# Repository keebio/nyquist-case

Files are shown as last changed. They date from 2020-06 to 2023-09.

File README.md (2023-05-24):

Nyquist Keyboard Case
=====================

Here's case design files for the [Nyquist](https://keeb.io/collections/nyquist-parts). It's a sandwich-style case with cutouts at the back to accomodate the USB jack and the TRRS jack.

There are a few different designs included in this repository, one case with 9 screw holes around the exterior of the plate (`exterior-screws` directory), and one with 4 screw holes on the interior of the plate (i.e. all but one screw is hidden from view) (`interior-screws` directory). The latest design is the [Enclosed Case](enclosed-case/) in the `enclosed-case` directory.

Exterior case pieces
--------------------
The design file for the exterior screw case has 2 top, 2 bottom, and 8 middle layer pieces. This is good for 1 complete case for 2 halves.

There's 4 different types of pieces the case uses:

- Top/Switch layer - Each half uses 1 of these
    - There are 3 different versions
    - `switch-layer-1u.svg` - All 1u keys
    - `switch-layer-2u.svg` - 2u key at lower right (or lower left if plate is flipped for other half)
    - `switch-layer-universal.svg` - Supports both 1u and 2u configuration
- Bottom layer (`bottom-layer.svg`) - Each half uses 1 of these
- Middle layer (`middle-layer.svg`)
    - C-shaped piece - Each half uses 3 of these, use a 4th one if you need more space (like when using a Pro Micro with Mini USB jack)
    - Stick piece - Same number as the C-Shaped piece

There is also an alternative middle layer file (`middle-layer-tent.svg`) that has 3 holes on the sides of it to allow for testing using 3 screws. **Note:** This tenting design needs to be reworked, as with all 3 screws in, it's somewhat unstable, but is fine with 2 screws on the one side.

Enclosed Case
-------------

The enclosed case pieces are designed for use with a 1.5mm plate from the `exterior-screws` folder. They are for use with the Nyquist Rev. 3.5 and Rev. 4 PCBs only.

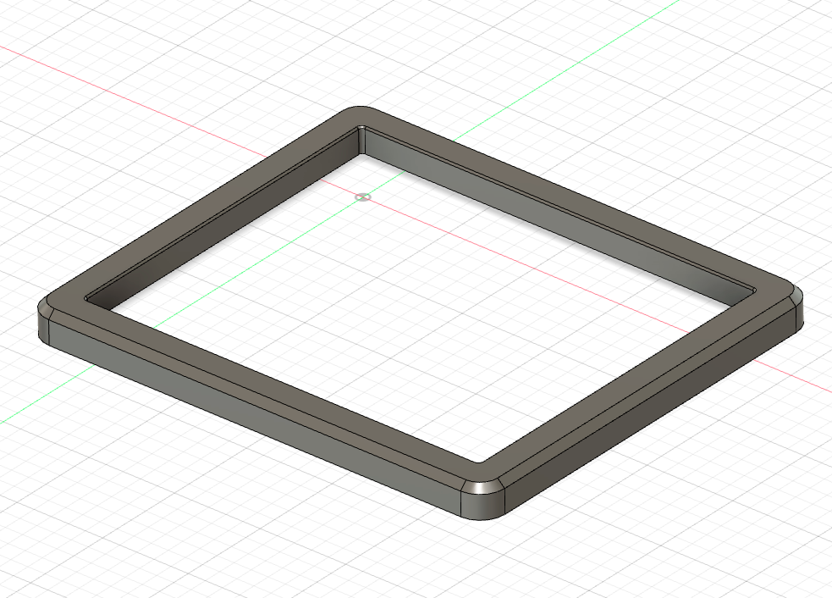
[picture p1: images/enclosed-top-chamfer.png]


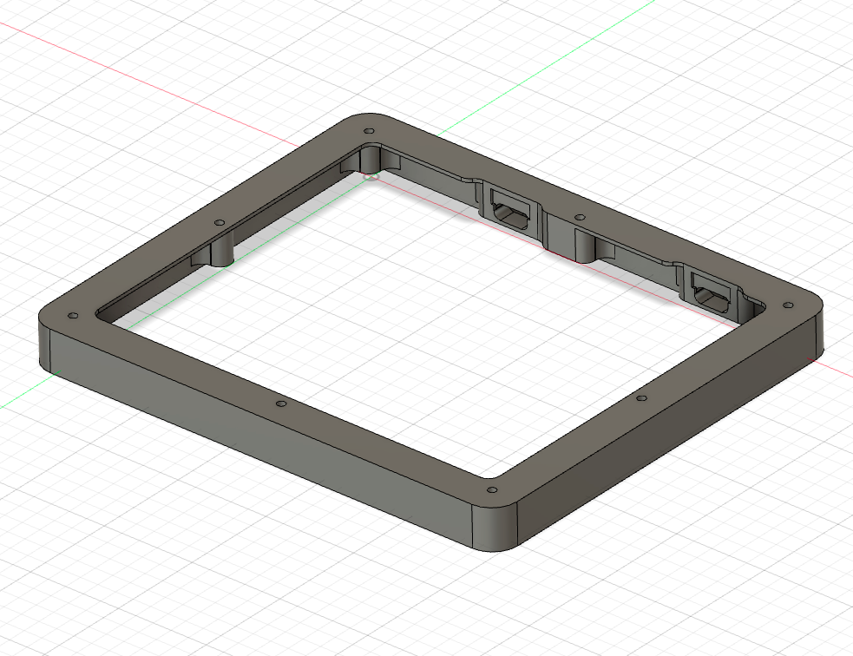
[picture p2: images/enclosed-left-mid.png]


Jeffeb3 3D printed/PCB case
---------------------------
Using the exterior screw PCB case, there is a 3D printed case designed with 3D printed tenting pegs.

Details [here](jeffeb3_case/README.md)

Interior case pieces
--------------------

There's only 2 different types of pieces the case uses:

- Top/Switch layer - Each half uses 1 of these
    - There are 2 different versions
    - `switch-layer-1u.svg` - All 1u keys
    - `switch-layer-universal.svg` - Supports both 1u and 2u configuration
- Bottom layer (`bottom-layer.svg`) - Each half uses 1 of these

Screws and Standoffs
--------------------
This case was designed to use M2 screws and standoffs. The holes in the middle layers are for the standoffs, while the holes in the top and bottom layers are only wide enough for the screws. M2 screws and standoffs that fit the case can be purchased at Keebio: [M2 Screws & Standoffs](https://keeb.io/products/m2-screws-and-standoffs)

Ponoko
------

### Arranging the Ponoko design yourself
To have the case made with Ponoko, you can't take the .svg files as is and send them off to them. First, you'll need to download the templates for P1, P2, & P3 sheets from here, depending on what vector editor you are using:

- [Inkscape templates](https://www.ponoko.com/starter-kits/inkscape)
- [Adobe Illustrator template](https://www.ponoko.com/starter-kits/adobe-illustrator)
- [Other](https://www.ponoko.com/make-and-sell/design-it-yourself)

Next, open up the template of the sheet size you want and open up the case design files as well. Then, copy the drawings in the case design files into the template. Remove any overlapping lines to reduce the cutting cost using this guide: [Avoid doubled up lines](http://support.ponoko.com/hc/en-us/articles/220289608-Avoid-doubled-up-blue-cutting-lines-in-your-designs).

### Pre-made Ponoko designs
If you don't want to arrange the pieces yourself, there are a couple of files included that are ready to be sent off to Ponoko:

- `P2-nyquist-v1-ponoko.eps`
    - Complete case for both halves
    - You only need to make one of these on a P2 sheet
- `P1-nyquist-middle.eps`
    - 2 middle layer pieces
    - If doing 3mm (0.118 in) thickness, you'll need 3 or 4 P1 sheets to get to 9mm or 12mm of total thickness respectively
    - If doing 4mm (0.177 in) thickness, you'll need 2 P1 sheets to get to 9mm thickness

## Middle Layer Thickness
If you're having the middle layers made, from the top of the switch plate to the top of the bottom plate, the minimium distance between the two required is 12mm if the plastic on the header pins is removed. The requirement is slightly more (about 13.5mm) if you leave the plastic on. Therefore, the following middle layer thickness are needed based on the thickness of the switch layer:

- 1.5mm Stainless steel switch plate: 10.5mm
    - Usually accomplished with:
        - 2x4.5mm + 1x1.5mm layers
        - or 3x3mm + 1x1.5mm layers
        - or 4x3mm layers
- 3mm acrylic switch plate: 9mm
    - Usually accomplished with:
        - 2x4.5mm layers
        - or 3x3mm layers

License
-------
These case files are released under the MIT License.

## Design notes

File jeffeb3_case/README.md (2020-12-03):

# 3D Printed Case for Nyquist Rev3.

**by jeffeb3**

This case is for the Nyquist Rev 3 keyboard from keeb.io. This case is intended to be 3D printed,
and fits on most modern FDM printers comfortably. It uses the PCB/FR4 top plate from keeb.io, which
gives it a great looking finish.

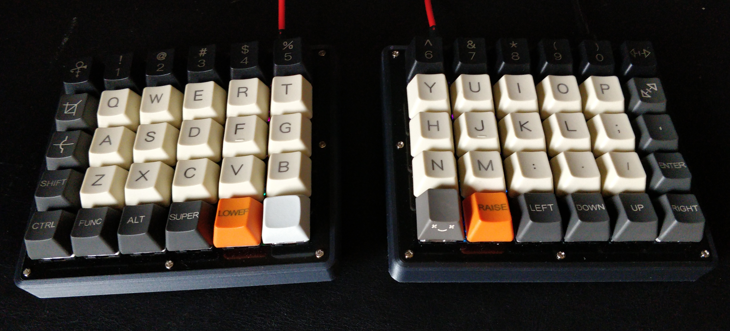
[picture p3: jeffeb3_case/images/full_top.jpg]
overview


_This is using 4x 10mm pegs only_

### Parts Needed

I built the Nyquist Rev3 from parts from
[keeb.io](https://keeb.io/collections/frontpage/products/nyquist-keyboard). First, follow those
instructions and advice for getting a functional keyboard.

This also uses the [PCB/FR4 case from
keeb.io](https://keeb.io/collections/cases-plates/products/stainless-steel-nyquist-plates). I used
this case first, and it is cleaner, and more accurate than a top plate that I can 3D print. It also
isn't very expensive, and makes a good interim/backup case.

Rough parts list:
 - [Keeb.io Nyquist Rev3 PCB](https://keeb.io/collections/frontpage/products/nyquist-keyboard)
 - Switches
 - Keycaps
 - [PCB Case top](https://keeb.io/collections/cases-plates/products/stainless-steel-nyquist-plates)
 - 16x PCB Case M2 screws
 - TRRS cable, USB C cable

3D Printed parts list:
- [Case right, for the right keyboard](Nyquist_Case-case_right.stl)
- [Case left, for the left keyboard](Nyquist_Case-case_left.stl)
- [4x tall pegs](Nyquist_Case-peg_15.stl)
- [4x small pegs, or leave them blank for the lowest profile](Nyquist_Case-peg_5.stl)

### Tenting

Tenting is accomplished by custom pegs. There are four holes for pegs in the corners. They are close
enough to the corners to provide stability, and you can print the length of pegs you want to
completely customize the fit.

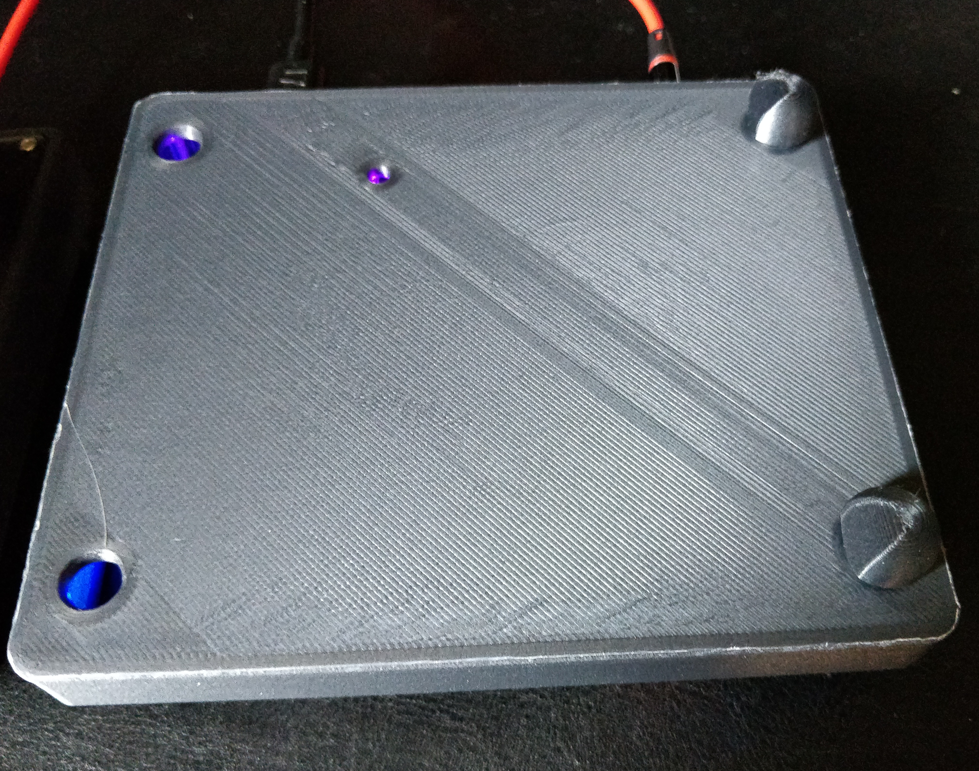
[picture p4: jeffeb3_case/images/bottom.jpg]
bottom


Included are STL files for various lengths of pegs. The number suffix roughly indicates the length
of the peg from the base of the case to the tip, but it might be 0.25mm-0.5mm off, because of the
various round overs and chamfers. If you want an in between size, scale the height in your slicer
from the closest length. It should scale well enough to change it a few millimeters.

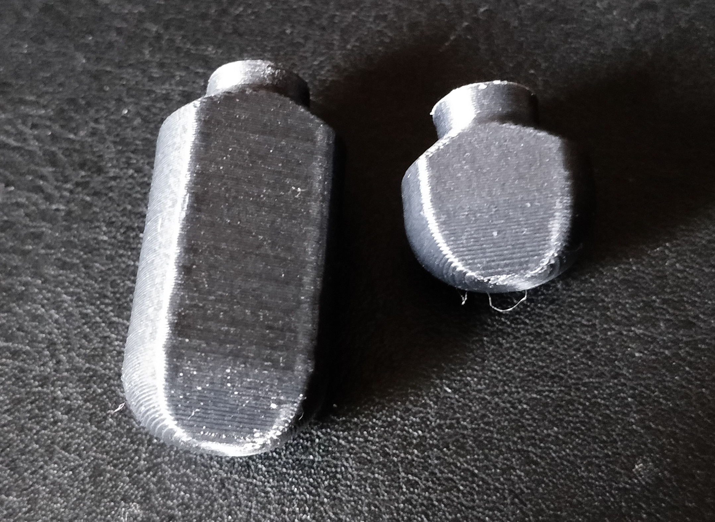
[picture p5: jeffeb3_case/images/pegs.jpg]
pegs


### RGB LEDs underneath

I have black filament in the printer right now. I think this would work well enough with clear or
maybe even white filament. If you print a case with a lighter filament, share some pretty images of
the lights with me, please. :)

### Printing

**Tips**

The cases are large enough that warping is a high risk. I printed them with a brim and they cleaned
up nicely.

The pegs have a small surface area and are pretty tall, so I also printed them with a brim. These
brims clean up nicely, and they don't affect the fit.

I printed with 3 perimeters, 6 top/bottom layers/30% infill, which are my goto settings for
functional prints. They are rock solid and very stiff, even when I'm hammering on the keys.

### Enjoy, share

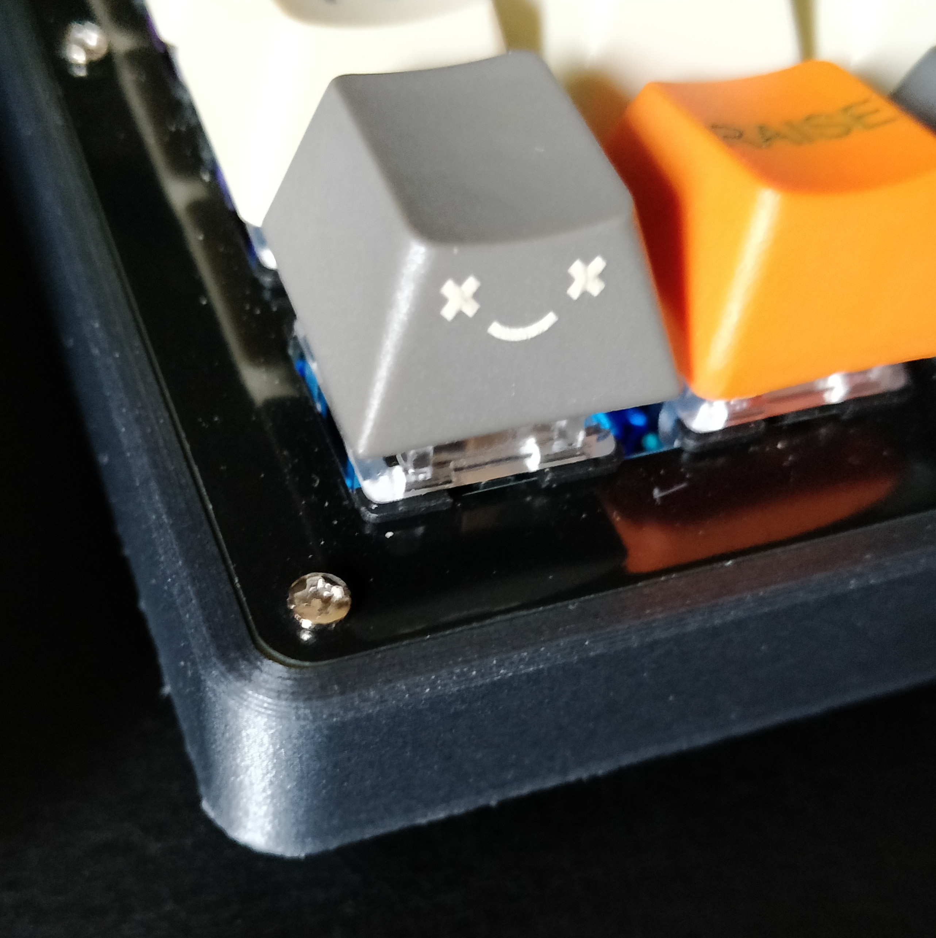
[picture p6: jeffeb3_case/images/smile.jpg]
smile


Please let me ([@jeffeb3, on github](https://github.com/jeffeb3), or on [twitter](https://twitter.com/jeffeb3)) know if you build this case. I like to know about
how people are using the stuff I share. :+1:

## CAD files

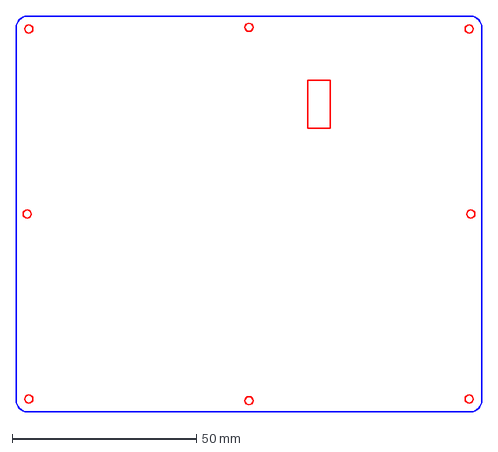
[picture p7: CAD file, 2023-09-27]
enclosed-case/Nyquist Bottom Plate.dxf
126.3 x 107.3 mm

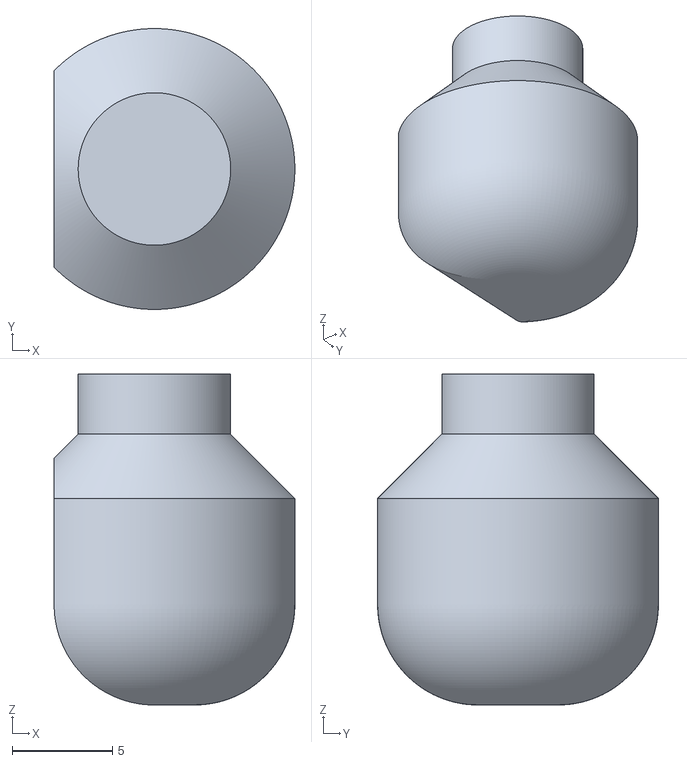
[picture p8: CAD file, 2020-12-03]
jeffeb3_case/Nyquist_Case-peg_12.5.stl
12.0 x 14.0 x 16.5

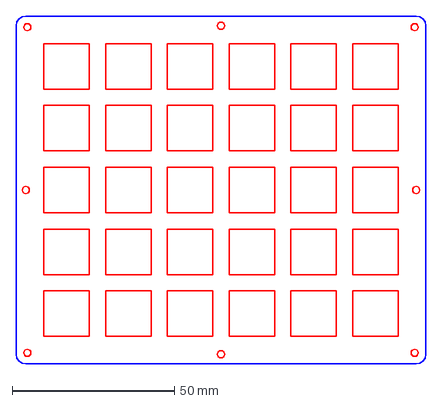
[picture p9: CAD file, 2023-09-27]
enclosed-case/Nyquist Switch Plate 1u-only.dxf
126.3 x 107.3 mm

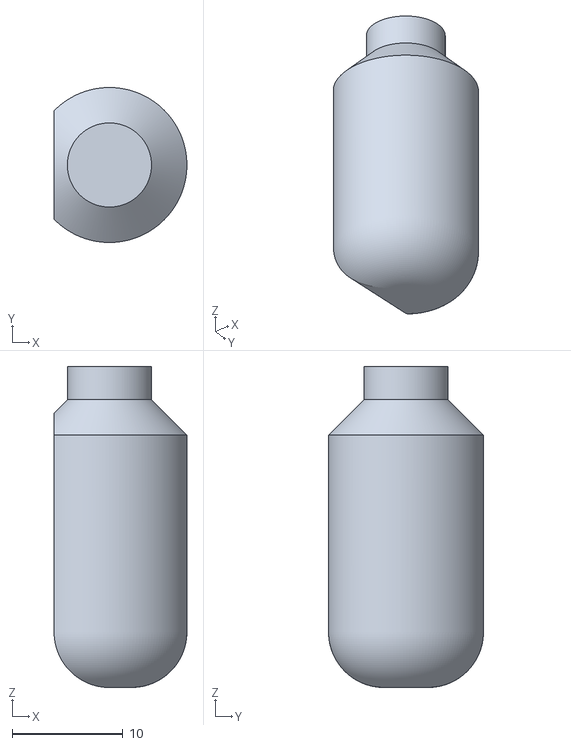
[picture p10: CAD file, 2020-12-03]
jeffeb3_case/Nyquist_Case-peg_25.stl
12.0 x 14.0 x 29.0

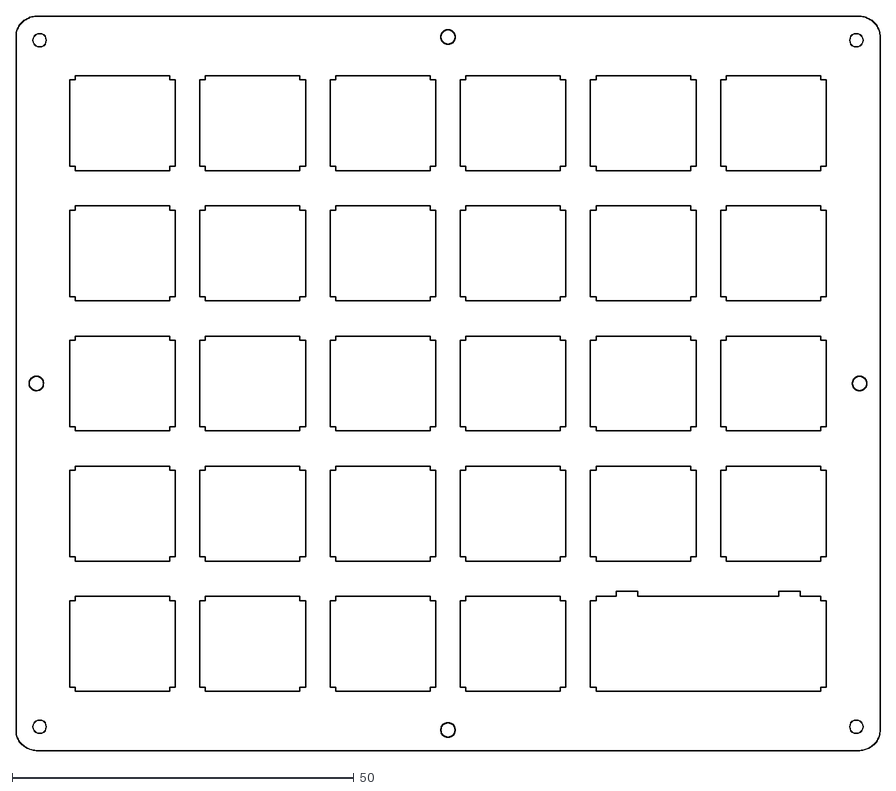
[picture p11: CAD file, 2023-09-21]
enclosed-case/Nyquist Switch Plate.dxf
126.4 x 107.4

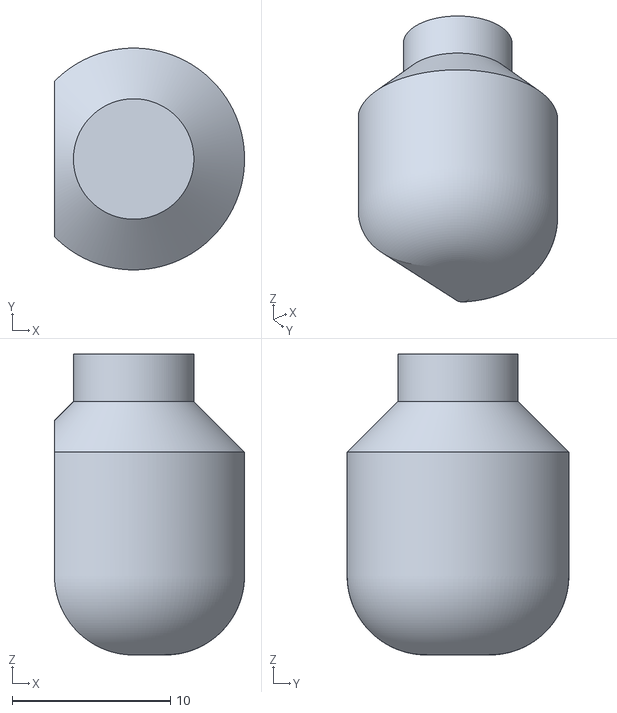
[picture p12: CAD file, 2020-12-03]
jeffeb3_case/Nyquist_Case-peg_15.stl
12.0 x 14.0 x 19.0

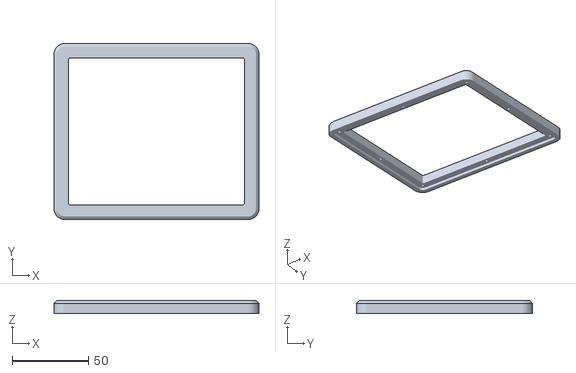
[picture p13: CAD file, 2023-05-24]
enclosed-case/Nyquist Top Shell - Chamfered.stl
134.3 x 115.2 x 8.70

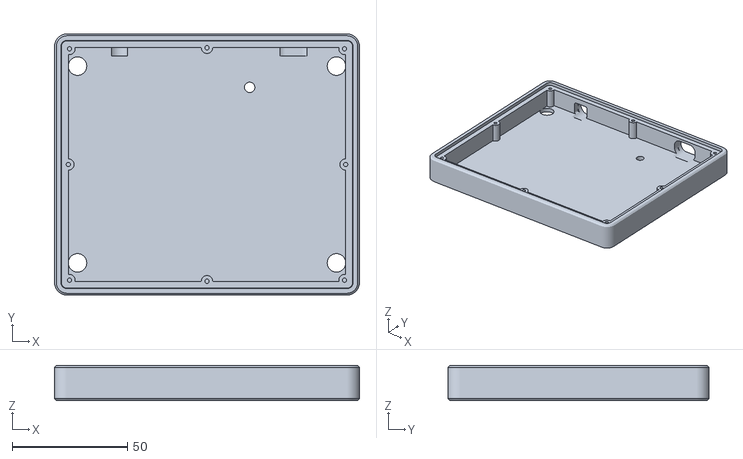
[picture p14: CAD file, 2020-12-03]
jeffeb3_case/Nyquist_Case-case_right.stl
132.3 x 113.4 x 15.2

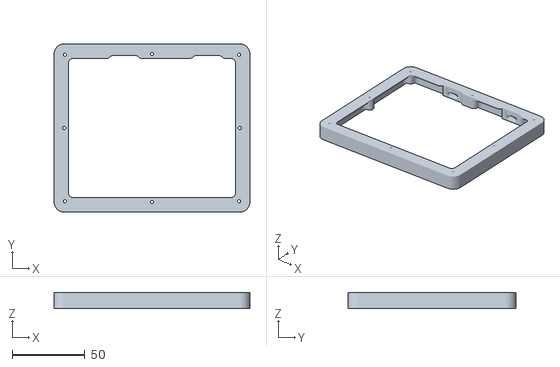
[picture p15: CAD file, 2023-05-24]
enclosed-case/Nyquist Mid Layer Left.stl
134.3 x 115.2 x 11.2

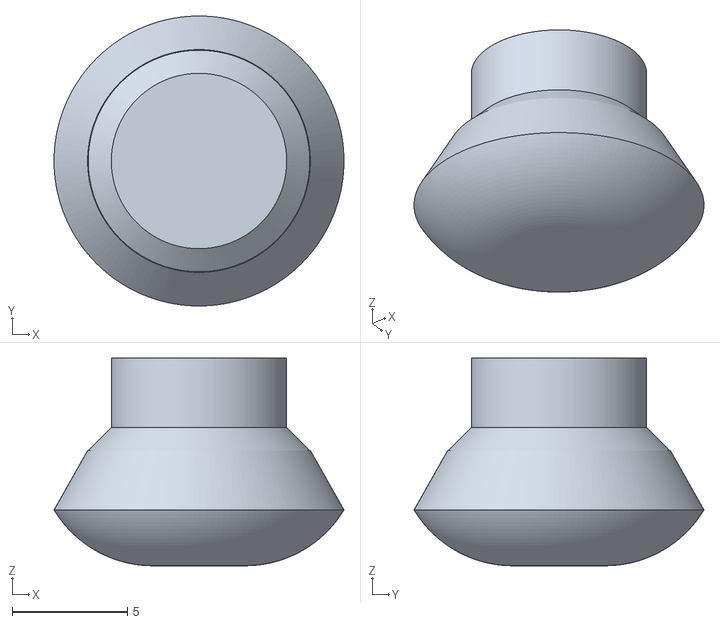
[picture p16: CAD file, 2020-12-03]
jeffeb3_case/Nyquist_Case-peg_5.stl
12.6 x 12.6 x 9.00

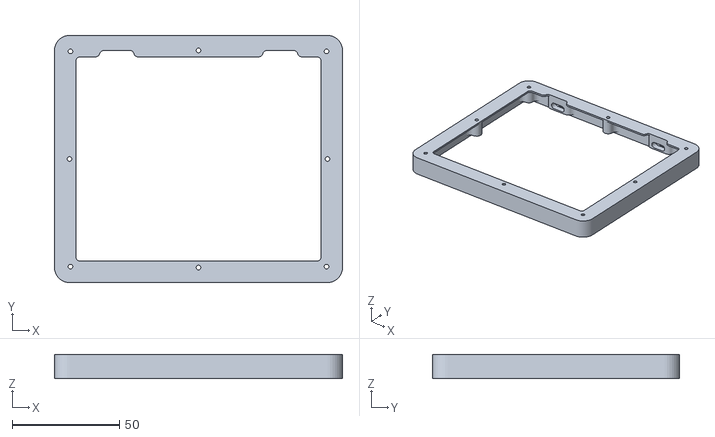
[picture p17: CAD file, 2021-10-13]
enclosed-case/Nyquist Mid Layer Right.stl
134.3 x 115.2 x 11.2

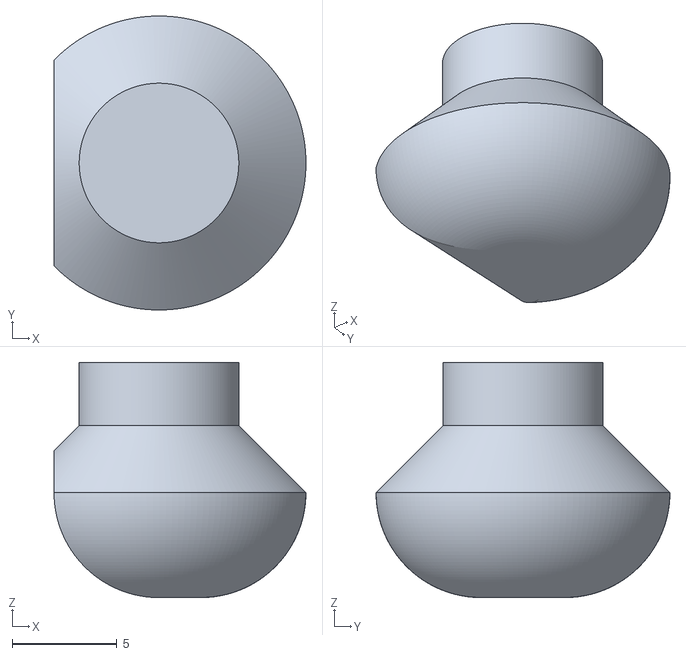
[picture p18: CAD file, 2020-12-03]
jeffeb3_case/Nyquist_Case-peg_7.2.stl
12.0 x 14.0 x 11.2

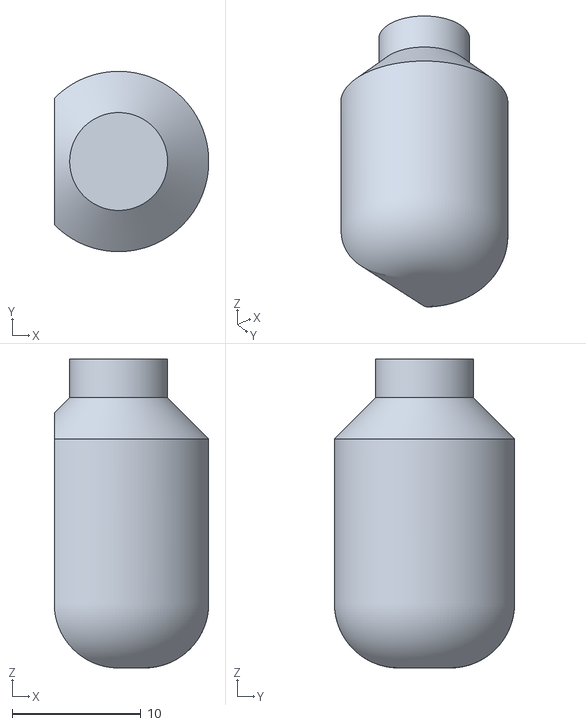
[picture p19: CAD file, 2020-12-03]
jeffeb3_case/Nyquist_Case-peg_20.stl
12.0 x 14.0 x 24.0

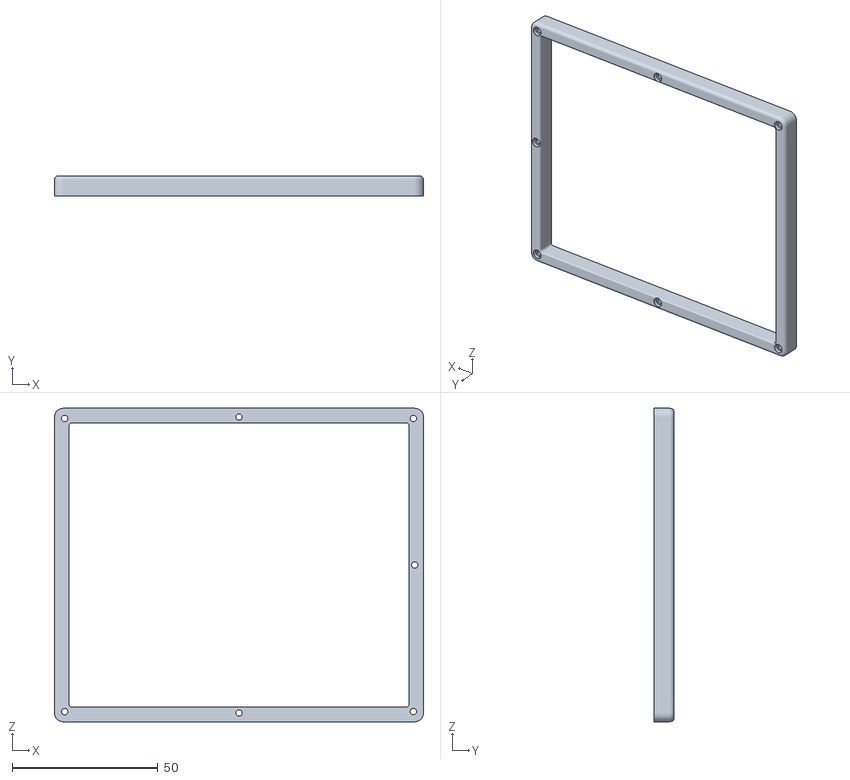
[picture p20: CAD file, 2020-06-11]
exterior-screws/Nyquist Top Shell.stl
126.4 x 7.00 x 107.4

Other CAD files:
enclosed-case/Nyquist Top Shell - Filleted.stl
jeffeb3_case/Nyquist_Case-case_left.stl

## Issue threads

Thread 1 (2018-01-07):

Steel/Aluminum Fabrication Question

Serubin, 2018-01-07:
What's the best way to cut for steel/aluminum? Could this be done on a CNC machine or are the 90 degree corners important for the switch layer?

Thanks!

nooges, 2018-01-10:
I get my plates done at a local shop that does laser cutting. Dunno how CNC would work out. I do have the stainless steel plates available on the store now though if you are interested.

Closed 2018-01-10.

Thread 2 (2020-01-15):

Top shell for Nyquist with external screws?

jezdez, 2020-01-15:
Hey there, I was wondering if you've considered providing an STL file for a top shell like you do for the [Levinson](https://github.com/keebio/lets-split-levinson-case/blob/e76fccac8d259de70456aa885871d4f2c2043cff/levinson/Levinson%20-%20Top%20Shell.stl) or [Iris](https://github.com/keebio/iris-case/blob/0119dde09887e29029c56cdb73e0645ad5ef3c54/Iris%20Hi-Pro%20Top%20-%20Thin%20Rim.stl) but for the Nyquist?

nooges, 2020-06-11:
Whipped up a top shell quickly (untested) and added it here: https://github.com/keebio/nyquist-case/blob/master/exterior-screws/Nyquist%20Top%20Shell.stl

jezdez, 2020-06-11:
Wooohoo, thank you @nooges!

Closed 2020-06-11.

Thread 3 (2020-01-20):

External bottom layer for rev3 with reset button hole?

jezdez, 2020-01-20:
Hey @nooges, would you mind sharing the location of the reset buttons on the rev3 so I can update the bottom layer files?

nooges, 2020-01-21:
Here's the export of the FR4 plate bottom:
[nyquist-bottom-brd.svg.zip](https://github.com/keebio/nyquist-case/files/4088687/nyquist-bottom-brd.svg.zip)

jezdez, 2020-01-22:
Hey thank you, much appreciated!

Closed 2020-06-11.

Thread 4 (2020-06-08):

Nyquist Rev 3 interior screws

rjcon, 2020-06-08:
Could we get a new layout file for the interior screws on the Nyquist Rev 3? They seem to have changed position and size.

nooges, 2020-06-11:
Added to https://github.com/keebio/nyquist-case/tree/master/pcb-outlines

Closed 2020-06-11.

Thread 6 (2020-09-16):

Interior case files

m4ceofspades, 2020-09-16:
Can a comment be added to the interior case files section in the readme that the holes only work for the v2. I ordered brass plates that I'm now having to redrill since I have the v3 board and the screw locations are different.

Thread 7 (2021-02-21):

Anyway to get the case files updated for the version 3.5

UtamaruMonster, 2021-02-21:
Good day,

Anyway to get the case files updated for the Nyquist 3.5 where each half has two USB-C ports?

Thank you.

pixelcatwave, 2022-10-14:
Echoing this, what program did oyu use to creat the stl files? Do you think you could export this in another format that woudl work better with fusion 360? Thanks! I want to modify the design a bit.

jeffeb3, 2022-10-14:
I don't have a v3.5 nyquist, so I can't update the files. I made the original files in onshape: https://cad.onshape.com/documents/b37387c32fced19f6f087da2/w/91ab7bae02e4e6f2a7885460/e/ba2df90d34c64191ba5562c0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

There is a free subscription if you are not using it for commercial purposes. I would recommend trying that before using the step files, since the changes you want are probably just changing a few numbers in the design.

But here are the step files too. Sorry for the zip, github won't let me attach a step file:
[nyquist_step.zip](https://github.com/keebio/nyquist-case/files/9787703/nyquist_step.zip)

BTW, I am still using this case every day with my nyquist and I can't think of any way I would improve it. I have some cheap mousepads with builtin wrist rests.

pixelcatwave, 2022-10-14:
Thank you! No the case looks great! I just want to make the lip a bit higher to hide the switches more and avoid having the keys catch on anything ie a high profile case.

jeffeb3, 2022-10-14:
When you're finished, you could submit it as a PR here. I'm sure keebio would accept anything that updates the files for future users.

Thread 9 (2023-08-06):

Some USB plugs won't fit with 3D printed enclosed case for rev4

weboide, 2023-08-06:
Hi,
I've just 3D printed the enclosed case for my rev4, but there are some USB cables that won't fit. The coiled USB cable from Keebio fits just barely when I apply pressure on the PCB. I'm guessing part of the problem is probably due to the tolerances in 3D printing (I printed it with adaptive layers and 0.2mm layer height) but it looks like it just needs a tiny bit thinner walls to work (maybe hot end tip smaller than 0.4mm would allow for thinner walls to be printed).
Regardless, if the wall section was just a tad thinner that might solve the problems for users who choose to 3D print it in the future.

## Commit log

2017-06-21 Add 2u and universal versions of switch layer
2017-08-04 Add plates with interior screws
2017-08-04 Add all 1u version of interior plates
2017-08-04 Move files for exterior screw case to subdirectory
2020-06-10 Added Rev. 3 PCB outlines
2020-06-11 Add top shell
    [Nyquist Top Shell.stl]
2020-09-07 Added jeffeb3 case Nyquist Rev3.
    [Nyquist_Case-case_left.stl, Nyquist_Case-case_right.stl, Nyquist_Case-peg_12.5.stl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]
2021-10-13 Add enclosed case for Rev 3.5
    [Nyquist Rev. 3.5 Left Mid Layer.stl, Nyquist Rev. 3.5 Right Mid Layer.stl, Nyquist Top Shell.stl]
2023-05-24 Fix left mid, added info to readme
    [Nyquist Mid Layer Left.stl, Nyquist Mid Layer Right.stl, Nyquist Rev. 3.5 Left Mid Layer.stl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]
2023-09-21 Add plate files for Rev. 4
    [Nyquist Bottom Plate.dxf, Nyquist Switch Plate.dxf]
2023-09-27 Recreate switch plates and bottom plate with proper curves
    [Nyquist Bottom Plate.dxf, Nyquist Switch Plate 1u-only.dxf]
